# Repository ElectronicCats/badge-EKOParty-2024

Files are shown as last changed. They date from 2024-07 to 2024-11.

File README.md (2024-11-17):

# Badge EKO Party 2024
Badge Oficial de EKOPARTY 2024

## Getting started

1. Connect Badge via USB to your computer.
2. Open the serial port indicated for the badge on your computer through a program such as Arduino IDE, Putty or Screen at 115200 bauds.
3. The badge text should appear in the terminal.

## Tecnologia

- ESP32C6
- LEDs neopixel
- USB
- LoRa
- Buzzer
- OLED

## How to build the firmware

Check the [Developer guide](./firmware/README.md) to learn how to build the firmware from scratch.

## Gratitude
Do you want to say thank you? Tag these companies on social networks and show them your badge, thanks to them it is possible

- [ElectronicCats](https://electroniccats.com/)

## License

Electronic Cats invests time and resources providing this open source design, please support Electronic Cats and open-source hardware by purchasing products from Electronic Cats!

Designed by Electronic Cats.

Hardware released under an CERN Open Hardware Licence v1.2. See the LICENSE_HARDWARE file for more information.

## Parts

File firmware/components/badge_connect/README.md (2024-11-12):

# Badge Connect library (Binary version)

This library is designed to provide a simple API in order to communicate electronic badges over a WiFi mesh network. It works using the [ESPNOW protocol](https://docs.espressif.com/projects/esp-idf/en/stable/esp32/api-reference/network/esp_now.html) developed by Espressif Systems.

## Features

- Send and receive messages between badges (messages can be of any data type)
- Set the badge's type (e.g. "BSides", "DragonJAR", "Ekoparty", and "BugCON")
- Get the badge's type

## Requirements

- At least two ESP32 development boards
- ESP-IDF installed in your computer
- `make` installed in your computer (optional)

## Installation

Add badge_connect_bin as a git submodule in your project.

```bash
git submodule add https://github.com/ElectronicCats/badge_connect_bin.git firmware/components/badge_connect
```

## Usage

1. Include the library in your source code.

```c
#include "badge_connect.h"
```

2. Initialize the library in your code.

```c
badge_connect_init();
```

3. Implement the callback function that will be called when a message is received.

```c
void receive_data_cb(badge_connect_recv_msg_t* msg) {
    // Do something with the received message
}
```

4. Register the callback function.

```c
badge_connect_register_recv_cb(receive_data_cb);
```

5. Set the badge's type, choose one of the following:

```c
badge_connect_set_bsides_badge();
badge_connect_set_dragonjar_badge();
badge_connect_set_ekoparty_badge();
badge_connect_set_bugcon_badge();
```

6. Send a message to another badge.

```c
char* data = "Hello, world!";
badge_connect_send(data, strlen(data));
```

7. Compile and flash!

## Examples

There is a folder called `examples` in this repository, you can use the `Makefile` in each example to compile and flash the firmware.

1. Get `idf.py` to your terminal session, if you followed the Espressif IDF installation guide, use `get_idf`.

```bash
get_idf
```

2. Go to the example folder you want to compile. For example, the `send_int` one.

```bash
cd examples/send_int
```

3. Set the board type you are using, skip if you are using an `ESP32`. For example, `ESP32-C6`.

```bash
idf.py set-target esp32c6
```

4. Set the serial port where the board is connected. For example, `/dev/ttyUSB0`.

```bash
export PORT=/dev/ttyUSB0
```

5. Compile, flash, and monitor the output.

```bash
make all
```

## License

Electronic Cats invests time and resources in providing this open-source design, please support Electronic Cats and open-source hardware by purchasing products from Electronic Cats!

Designed by Electronic Cats.

This library is released under a GNU AGPL v3.0 license. See the [LICENSE](LICENSE) file for more information.

Electronic Cats is a registered trademark, please do not use if you sell these PCBs.

June 2024

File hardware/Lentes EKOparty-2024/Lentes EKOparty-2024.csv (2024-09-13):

Reference | Value | Datasheet | Footprint | Qty | DNP | #LCSC
J2 | Conn_02x03_Odd_Even | ~ | Connector_PinHeader_2.54mm:PinHeader_2x03_P2.54mm_Vertical | 1 |  | C706893

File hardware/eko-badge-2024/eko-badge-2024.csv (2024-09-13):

Reference | Value | Datasheet | Footprint | Qty | DNP | LCSC# | Proveedor | manf#
AE1 | Antenna_Shield |  | Connector_PinHeader_2.54mm:PinHeader_1x01_P2.54mm_Vertical | 1 | DNP | C2913580
C1,C3,C4,C5 | 10uF |  | Capacitor_SMD:C_0603_1608Metric | 4 |  | C85713 | JLCPCB | GRM188R61E106KA73J
C2,C15 | 1uF |  | Capacitor_SMD:C_0603_1608Metric | 2 |  | C15849 | JLCPCB | TMK107BJ105KA8T
C6,C7,C8,C9,C10,C11,C12,C14,C16,C17,C18 | .1uF |  | Capacitor_SMD:C_0603_1608Metric | 11 |  | C478888 | LCSC | 0603F104M500NT
C13 | .22uF |  | Capacitor_SMD:C_0603_1608Metric | 1 |  | C161213 | LCSC
D1 | MBR120 |  | Diode_SMD:D_SOD-123F | 1 |  | C130880 | JLCPCB | MBR120LSFT1G
D2,D3,D4 | WS2812B |  | LED_SMD:LED_WS2812B-Mini_PLCC4_3.5x3.5mm | 3 |  | C527089 | LCSC | WS2812B-Mini
F1 | 1A |  | Fuse:Fuse_0805_2012Metric | 1 |  | C2649564 | JLCPCB | MFU0805FF01000P100
J1 | UART |  | Connector_PinHeader_2.54mm:PinHeader_1x04_P2.54mm_Vertical | 1 | DNP
J2,J7 | Battery |  | Eko2024:BH-AA-A1AJ020 | 2 |  | C5290181 | JLCPCB y LCSC
J3 | Lentes |  | Eko2024:HARWIN_M20-7810345 | 1 |  |  | DIGIKEY | M20-7810345
J4 | OLED |  | Eko2024:Display OLED 128 x32 | 1 |  |  | UNIT | Display OLED 128×32 0.91 I2C SSD1306 Blanco / Azul
J5,J6 | Add-On |  | Connector_PinSocket_2.54mm:PinSocket_2x03_P2.54mm_Vertical_SMD | 2 |  | C3975148
LS1 | 931-SPKM.20.8.A-ND |  | Connector_PinHeader_2.54mm:PinHeader_1x02_P2.54mm_Vertical | 1 |  |  |  | 931-SPKM.20.8.A-ND
P1 | USB_C_Plug_USB2.0 |  | Eko2024:C393939 | 1 |  | C393939 | LCSC | TYPE-C-31-M-31
Q1 | DMG3415U-7 |  | Package_TO_SOT_SMD:SOT-23 | 1 |  | C96616 | JLCPCB | DMG3415UQ-7
R1 | 100K |  | Resistor_SMD:R_0603_1608Metric | 1 |  | C25803 | JLCPCB | RC0603DR-07100KL
R2 | 10K |  | Resistor_SMD:R_0603_1608Metric | 1 |  | C217281
R3,R4 | 5k1 |  | Resistor_SMD:R_0603_1608Metric | 2 |  | C191782 |  | ERJ3RBD5101V
R5 | 47K |  | Resistor_SMD:R_0603_1608Metric | 1 |  | C25819
R6 | 22K |  | Resistor_SMD:R_0603_1608Metric | 1 |  | C912502
R7 | 470 |  | Resistor_SMD:R_0603_1608Metric | 1 |  | C103661 |  | RTT03471JTP
R8 | 3.3K |  | Resistor_SMD:R_0603_1608Metric | 1 |  | C403480 | JLCPCB | ERJ-3GEYJ332V
SW1 | ON |  | Eko2024:MSK12C02 | 1 |  | C431540 | JLCPCB
SW2 | LEFT |  | Button_Switch_SMD:SW_SPST_TL3342 | 1 |  | C318889 | LCSC
SW3 | UP |  | Button_Switch_SMD:SW_SPST_TL3342 | 1 |  | C318889 | LCSC
SW4 | DOWN |  | Button_Switch_SMD:SW_SPST_TL3342 | 1 |  | C318889 | LCSC
SW5 | RESET |  | Button_Switch_SMD:SW_SPST_TL3342 | 1 |  | C318889 | LCSC
SW6 | BOOT |  | Button_Switch_SMD:SW_SPST_TL3342 | 1 |  | C318889 | LCSC
SW7 | RIGTH |  | Button_Switch_SMD:SW_SPST_TL3342 | 1 |  | C318889 | LCSC
U1 | ESP32-C6-WROOM-1-N4 |  | bsides:XCVR_ESP32-C6-WROOM-1-N8 | 1 |  |  | Mouser | ESP32-C6-WROOM-1-N4
U2 | XC6220B331MR-G |  | Package_TO_SOT_SMD:SOT-23-5 | 1 |  | C86534 | JLCPCB | XC6220B331MR-G
U3 | RFM95W-915S2 |  | RF_Module:HOPERF_RFM9XW_SMD | 1 |  |  | Mouser | 109990166
U4 | TPA321 |  | Package_SO:SOP-8_3.9x4.9mm_P1.27mm | 1 |  | C2873032 | Mouser | TPA321D

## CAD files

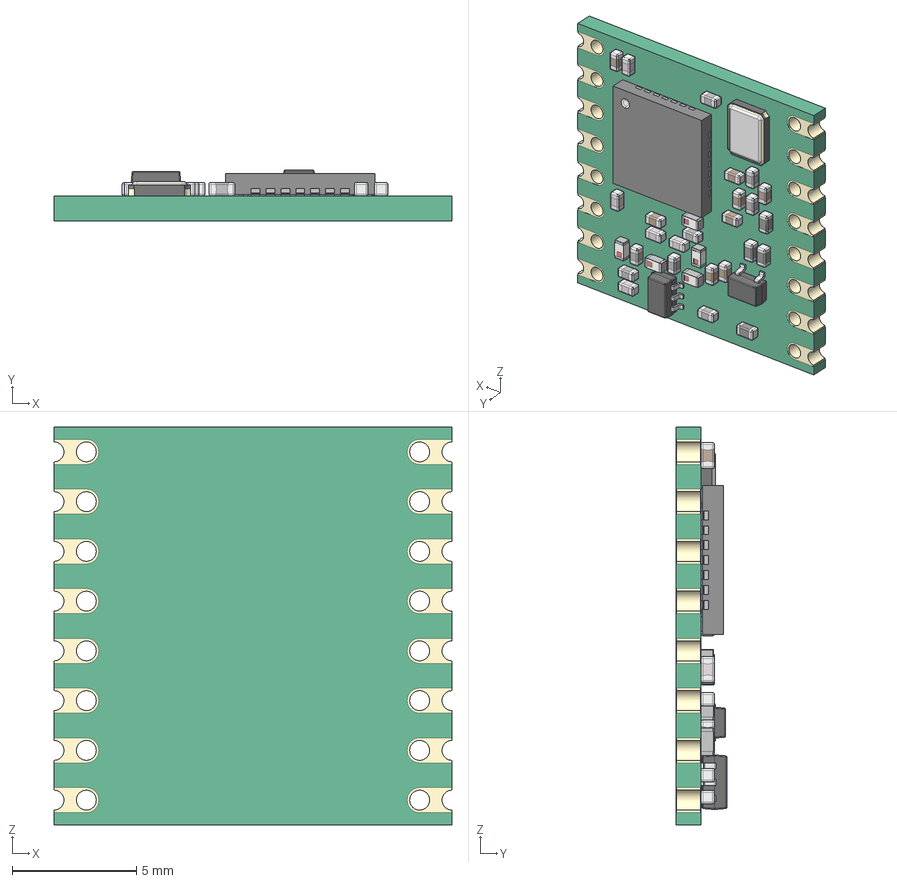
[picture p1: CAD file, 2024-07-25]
hardware/3D/RFM95 LoRa v15.step
16.0 x 2.04 x 16.0 mm
QFN 28
SMD Crystal
CAP 0403 x 8
CAP Ceramic 0403 x 8
Res 0403 x 4
CAP ML 0403 x 5
SOT-323
Inductor SMD 0403 x 5
SOT-363

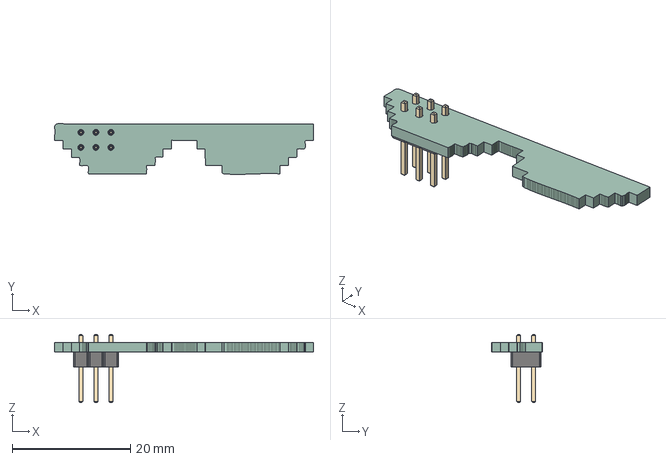
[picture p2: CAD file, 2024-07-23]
hardware/Lentes EKOparty-2024/Lentes EKOparty-2024.step
43.8 x 8.58 x 11.5 mm
PinHeader_2x03_P254mm_Vertical
Lentes EKOparty-2024_PCB

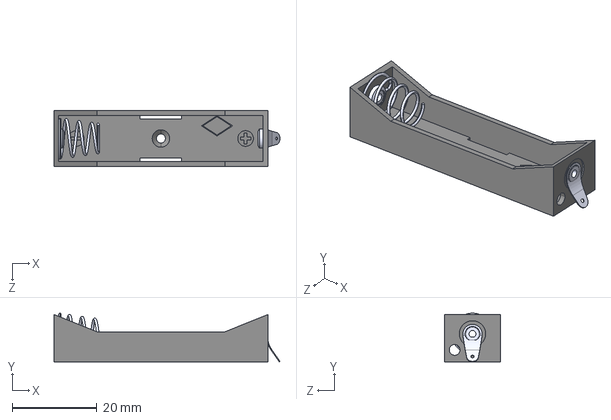
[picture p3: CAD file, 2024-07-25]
hardware/3D/BCAAAL.step
53.4 x 11.5 x 13.2 mm

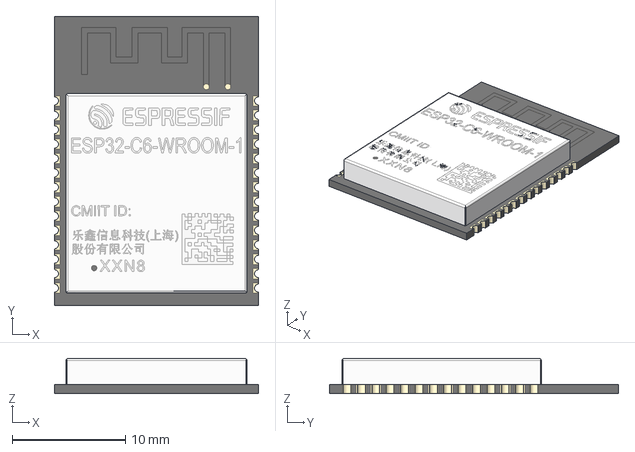
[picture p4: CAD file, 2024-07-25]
hardware/3D/ESP32-C6-WROOM-1-N4.step
18.0 x 25.5 x 3.11 mm

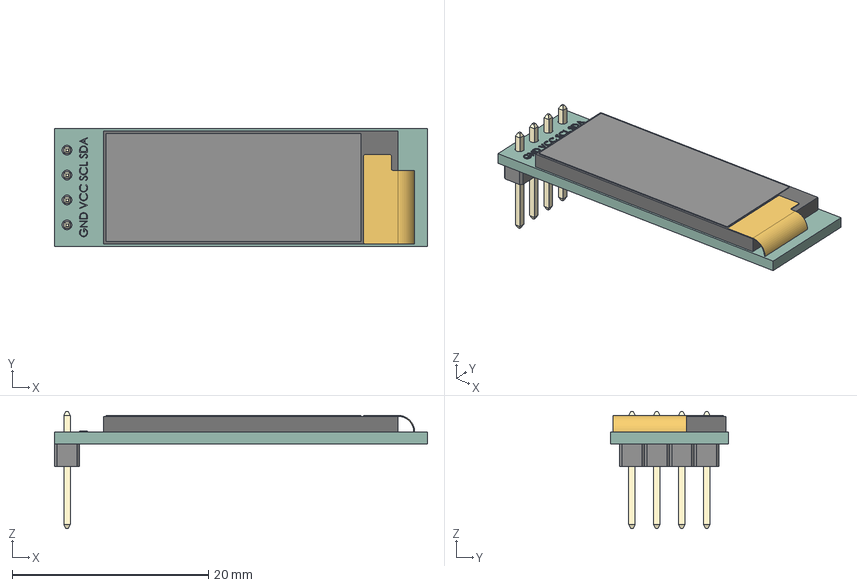
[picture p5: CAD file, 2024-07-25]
hardware/3D/128x32-OLED.STEP
38.0 x 12.0 x 11.9 mm

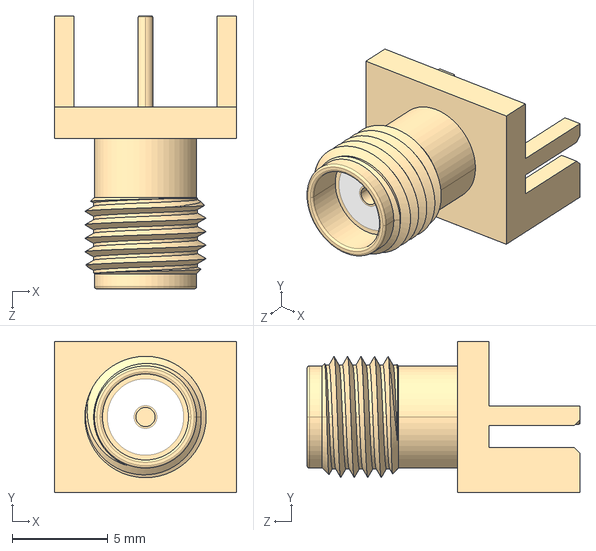
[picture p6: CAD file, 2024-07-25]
hardware/3D/2985-6036.STEP
9.53 x 7.92 x 14.3 mm

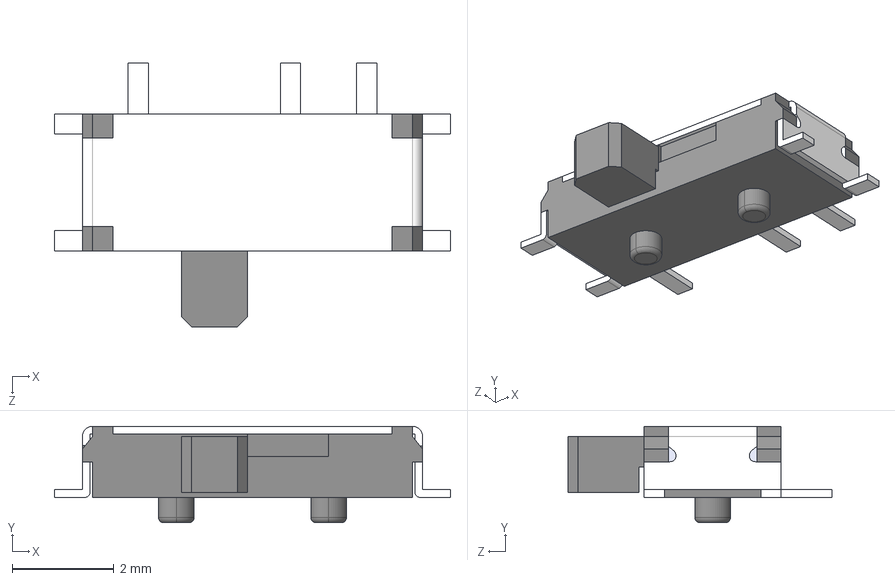
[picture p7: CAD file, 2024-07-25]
hardware/3D/MSK12C02.stp
7.80 x 1.90 x 5.20 mm

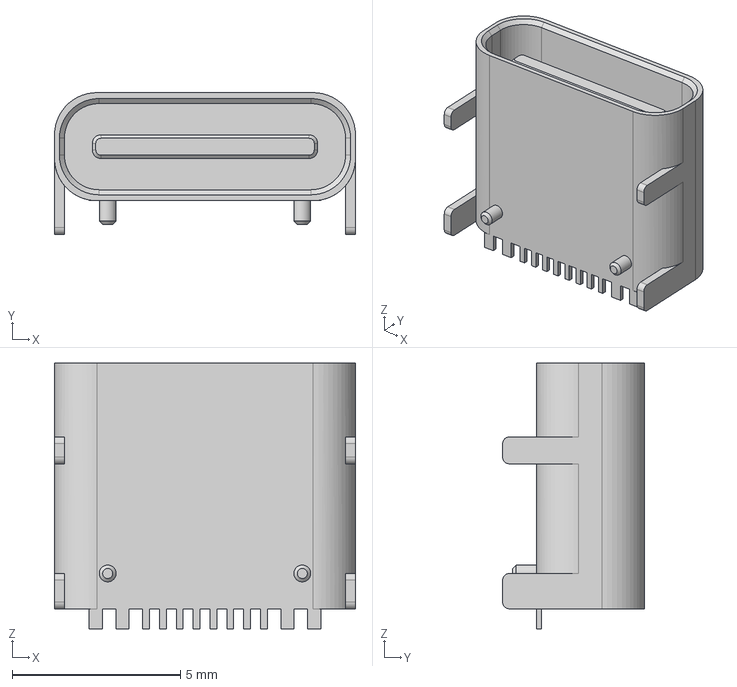
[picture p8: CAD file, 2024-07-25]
hardware/3D/HRO TYPE-C-31-M-12.step
8.94 x 4.21 x 7.90 mm

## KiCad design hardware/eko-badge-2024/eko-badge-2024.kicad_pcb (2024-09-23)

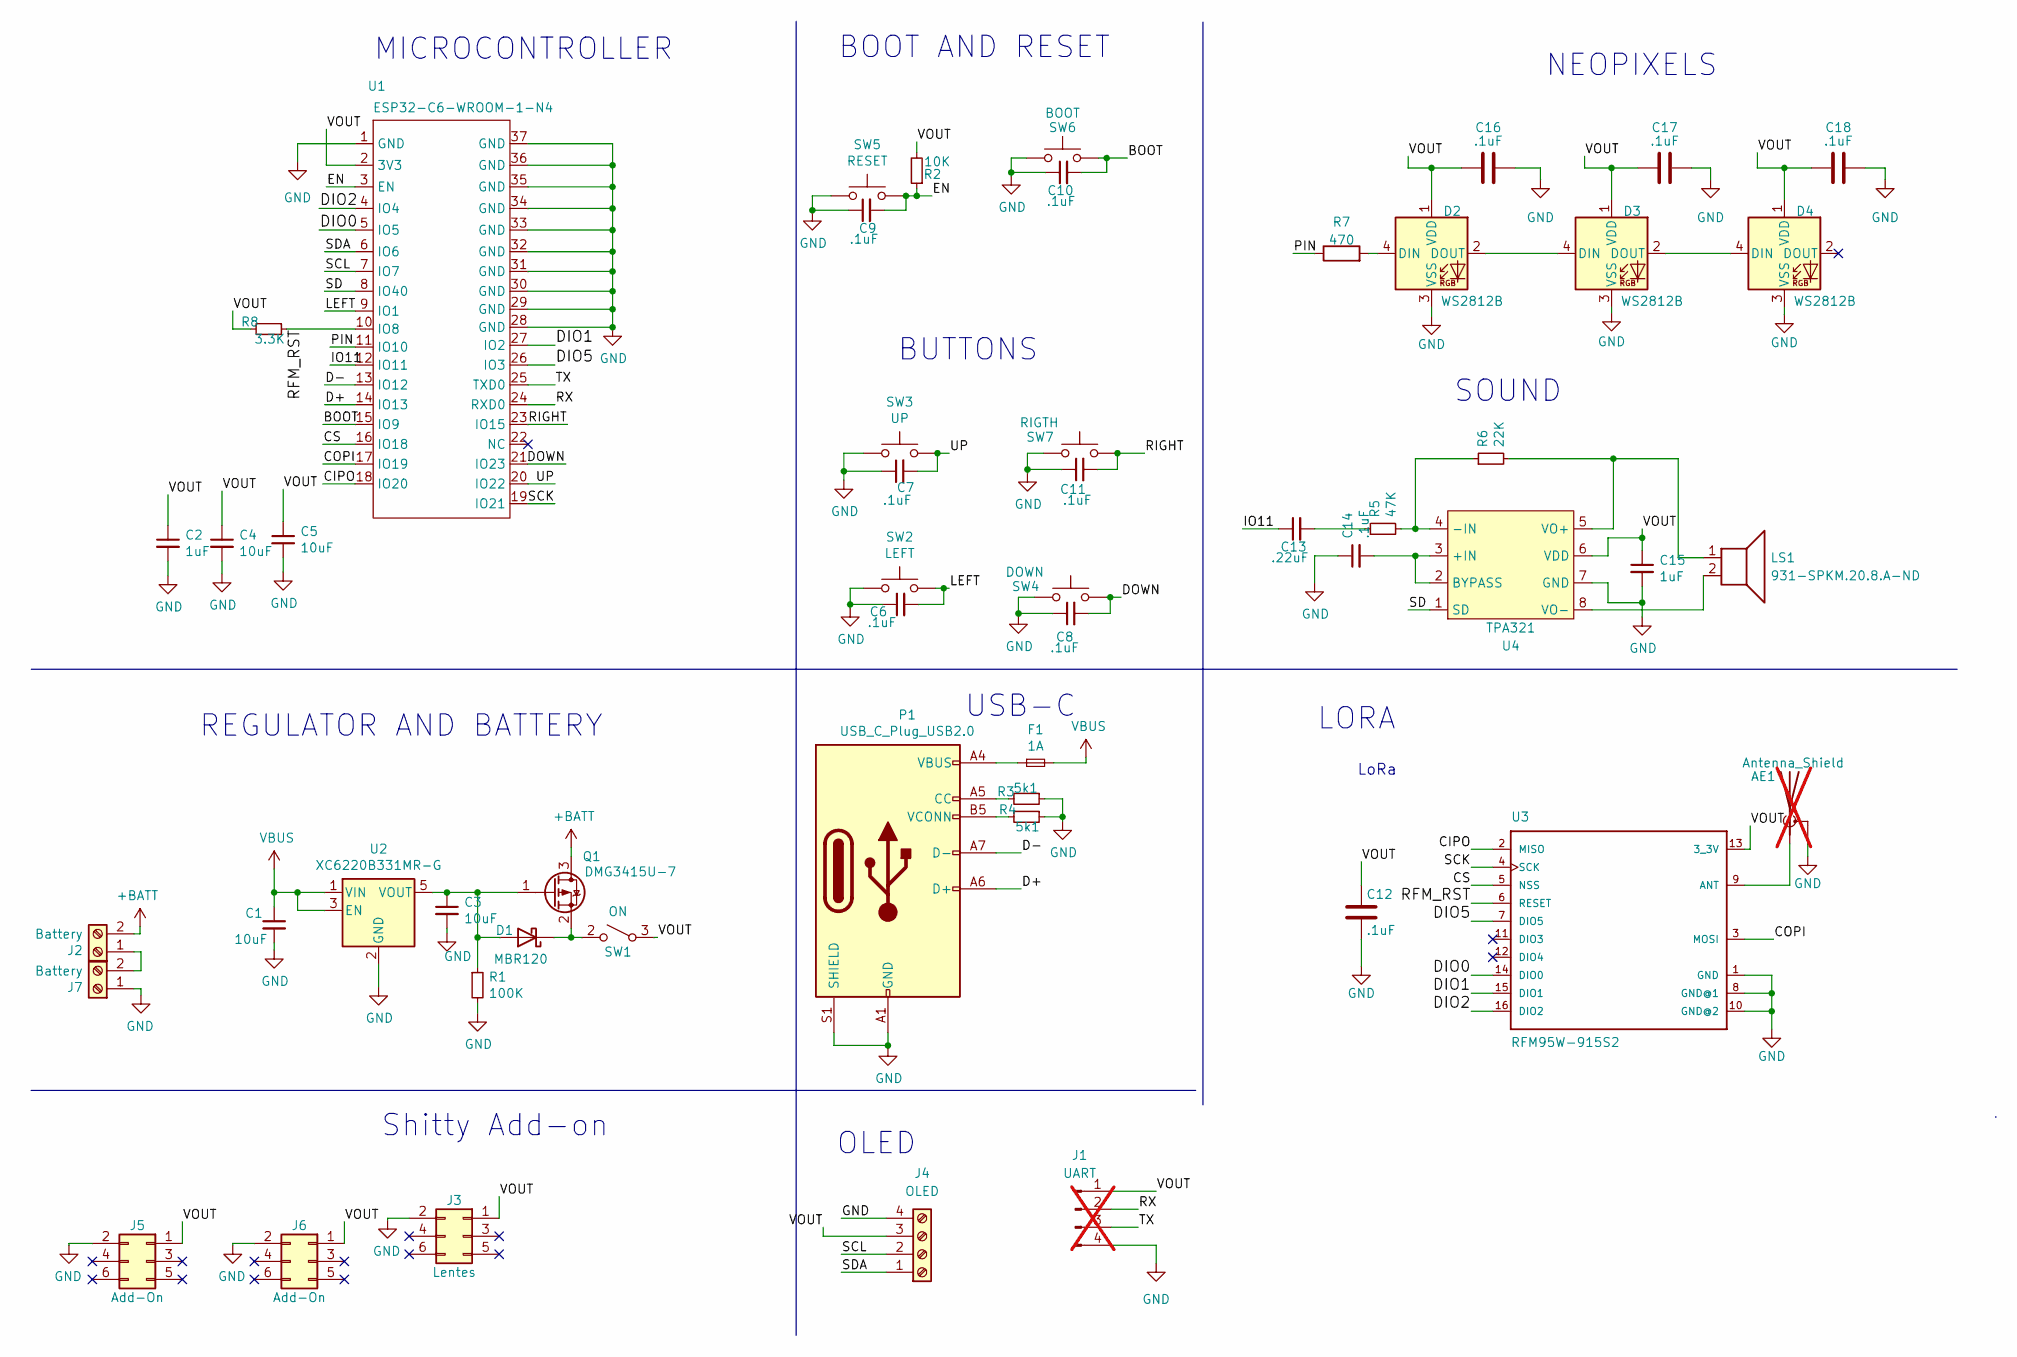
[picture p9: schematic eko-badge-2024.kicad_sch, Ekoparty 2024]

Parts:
AE1: Antenna_Shield; PinHeader_1x01_P2.54mm_Vertical; LCSC# C2913580; not fitted
C1, C3, C4, C5: 10uF; C_0603_1608Metric; LCSC# C85713
C2, C15: 1uF; C_0603_1608Metric; LCSC# C15849
C6, C7, C8, C9, C10, C11, C12, C14, C16, C17, C18: .1uF; C_0603_1608Metric; LCSC# C478888
C13: .22uF; C_0603_1608Metric; LCSC# C161213
D1: MBR120; D_SOD-123F; LCSC# C130880
D2, D3, D4: WS2812B; LED_WS2812B-Mini_PLCC4_3.5x3.5mm; LCSC# C527089
F1: 1A; Fuse_0805_2012Metric; LCSC# C2649564
J1: UART; PinHeader_1x04_P2.54mm_Vertical; not fitted
J2, J7: Battery; BH-AA-A1AJ020; LCSC# C5290181
J3: Lentes; HARWIN_M20-7810345
J4: OLED; Display OLED 128 x32
J5, J6: Add-On; PinSocket_2x03_P2.54mm_Vertical_SMD; LCSC# C3975148
LS1: 931-SPKM.20.8.A-ND; PinHeader_1x02_P2.54mm_Vertical
P1: USB_C_Plug_USB2.0; C393939; LCSC# C393939
Q1: DMG3415U-7; SOT-23; LCSC# C96616
R1: 100K; R_0603_1608Metric; LCSC# C25803
R2: 10K; R_0603_1608Metric; LCSC# C217281
R3, R4: 5k1; R_0603_1608Metric; LCSC# C191782
R5: 47K; R_0603_1608Metric; LCSC# C25819
R6: 22K; R_0603_1608Metric; LCSC# C912502
R7: 470; R_0603_1608Metric; LCSC# C103661
R8: 3.3K; R_0603_1608Metric; LCSC# C403480
SW1: ON; MSK12C02; LCSC# C431540
SW2: LEFT; SW_SPST_TL3342; LCSC# C318889
SW3: UP; SW_SPST_TL3342; LCSC# C318889
SW4: DOWN; SW_SPST_TL3342; LCSC# C318889
SW5: RESET; SW_SPST_TL3342; LCSC# C318889
SW6: BOOT; SW_SPST_TL3342; LCSC# C318889
SW7: RIGTH; SW_SPST_TL3342; LCSC# C318889
U1: ESP32-C6-WROOM-1-N4; XCVR_ESP32-C6-WROOM-1-N8
U2: XC6220B331MR-G; SOT-23-5; LCSC# C86534
U3: RFM95W-915S2; HOPERF_RFM9XW_SMD
U4: TPA321; SOP-8_3.9x4.9mm_P1.27mm; LCSC# C2873032

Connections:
+BATT: J2.2, Q1.3 (D)
/BOOT: C10.2, SW6.2, U1.15 (IO9)
/CIPO: U1.18 (IO20), U3.2 (MISO)
/COPI: U1.17 (IO19), U3.3 (MOSI)
/CS: U1.16 (IO18), U3.5 (NSS)
/D+: P1.A6 (D+), U1.14 (IO13)
/D-: P1.A7 (D-), U1.13 (IO12)
/DIO0: U1.5 (IO5), U3.14 (DIO0)
/DIO1: U1.27 (IO2), U3.15 (DIO1)
/DIO2: U1.4 (IO4), U3.16 (DIO2)
/DIO5: U1.26 (IO3), U3.7 (DIO5)
/DOWN: C8.2, SW4.2, U1.21 (IO23)
/EN: C9.2, R2.1, SW5.2, U1.3 (EN)
/IO11: C13.1, U1.12 (IO11)
/LEFT: C6.2, SW2.2, U1.9 (IO1)
/PIN: R7.1, U1.11 (IO10)
/RFM_RST: R8.1, U1.10 (IO8), U3.6 (RESET)
/RIGHT: C11.2, SW7.2, U1.23 (IO15)
/RX: J1.2, U1.24 (RXD0)
/SCK: U1.19 (IO21), U3.4 (SCK)
/SCL: J4.2, U1.7 (IO7)
/SD: U1.8 (IO40), U4.1 (SD)
/SDA: J4.1, U1.6 (IO6)
/TX: J1.3, U1.25 (TXD0)
/UP: C7.2, SW3.2, U1.20 (IO22)
/VOUT: C2.1, C4.1, C5.1, C12.1, C15.1, C16.2, C17.2, C18.2, D2.1 (VDD), D3.1 (VDD), D4.1 (VDD), J1.1, J3.1, J4.3, J5.1, J6.1, R2.2, R8.2, SW1.3 (A), U1.2 (3V3), U3.13 (3_3V), U4.6 (VDD)
GND: AE1.2 (Shield), C1.2, C2.2, C3.2, C4.2, C5.2, C6.1, C7.1, C8.1, C9.1, C10.1, C11.1, C12.2, C14.1, C15.2, C16.1, C17.1, C18.1, D2.3 (VSS), D3.3 (VSS), D4.3 (VSS), J1.4, J3.2, J4.4, J5.2, J6.2, J7.1, P1.A1 (GND), P1.A12 (GND), P1.B1 (GND), P1.B12 (GND), P1.S1 (SHIELD), R1.2, R3.1, R4.1, SW2.1, SW3.1, SW4.1, SW5.1, SW6.1, SW7.1, U1.1 (GND), U1.28 (GND), U1.29 (GND), U1.30 (GND), U1.31 (GND), U1.32 (GND), U1.33 (GND), U1.34 (GND), U1.35 (GND), U1.36 (GND), U1.37 (GND), U2.2 (GND), U3.1 (GND), U3.8 (GND@1), U3.10 (GND@2), U4.7 (GND)
unnamed: AE1.1 (A), U3.9 (ANT)
unnamed: C13.2, R5.1
unnamed: C3.1, D1.2 (A), Q1.1 (G), R1.1, U2.5 (VOUT)
unnamed: D1.1 (K), Q1.2 (S), SW1.2 (B)
unnamed: D2.4 (DIN), R7.2
unnamed: D2.2 (DOUT), D3.4 (DIN)
unnamed: D3.2 (DOUT), D4.4 (DIN)
unnamed: F1.1, P1.A4 (VBUS), P1.A9 (VBUS), P1.B4 (VBUS), P1.B9 (VBUS)
unnamed: J2.1, J7.2
unnamed: P1.A5 (CC), R3.2
unnamed: P1.B5 (VCONN), R4.2
unnamed: C14.2, U4.2 (BYPASS), U4.3 (+IN)
unnamed: R5.2, R6.1, U4.4 (-IN)
unnamed: LS1.1, R6.2, U4.5 (VO+)
unnamed: LS1.2, U4.8 (VO-)
VBUS: C1.1, F1.2, U2.1 (VIN), U2.3 (EN)

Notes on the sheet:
MICROCONTROLLER
LoRa
OLED
USB-C
BUTTONS
SOUND
LORA
NEOPIXELS
REGULATOR AND BATTERY
Shitty Add-on
BOOT AND RESET

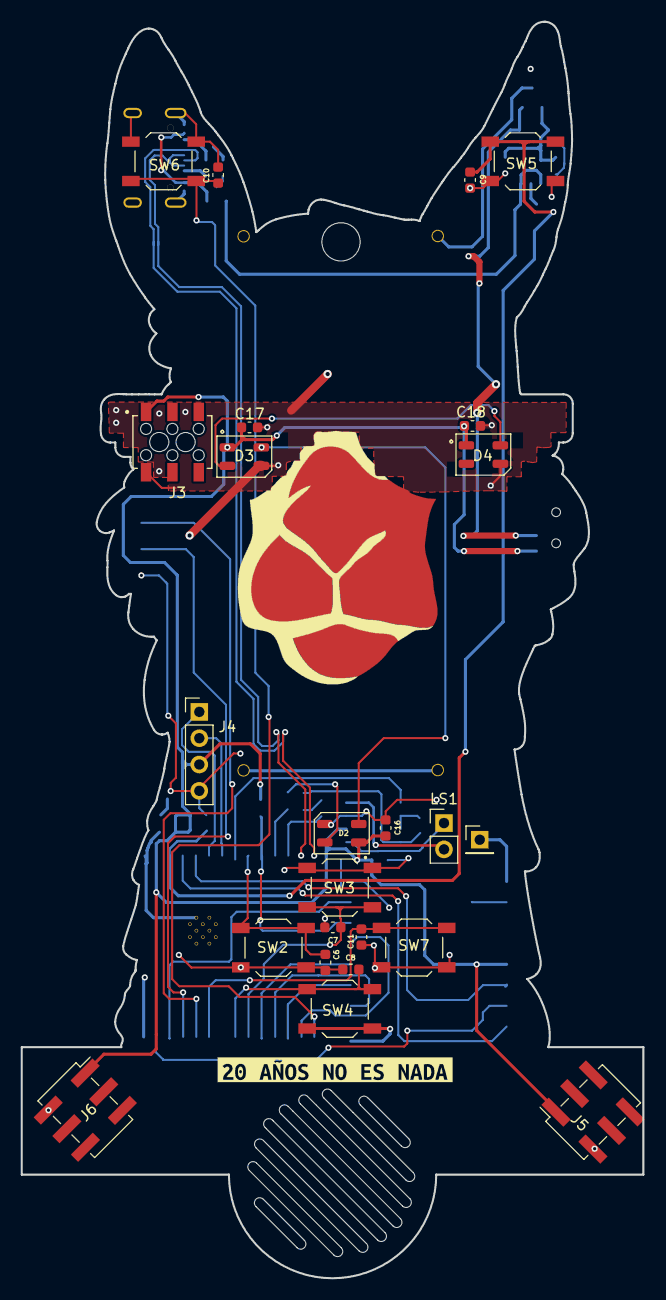
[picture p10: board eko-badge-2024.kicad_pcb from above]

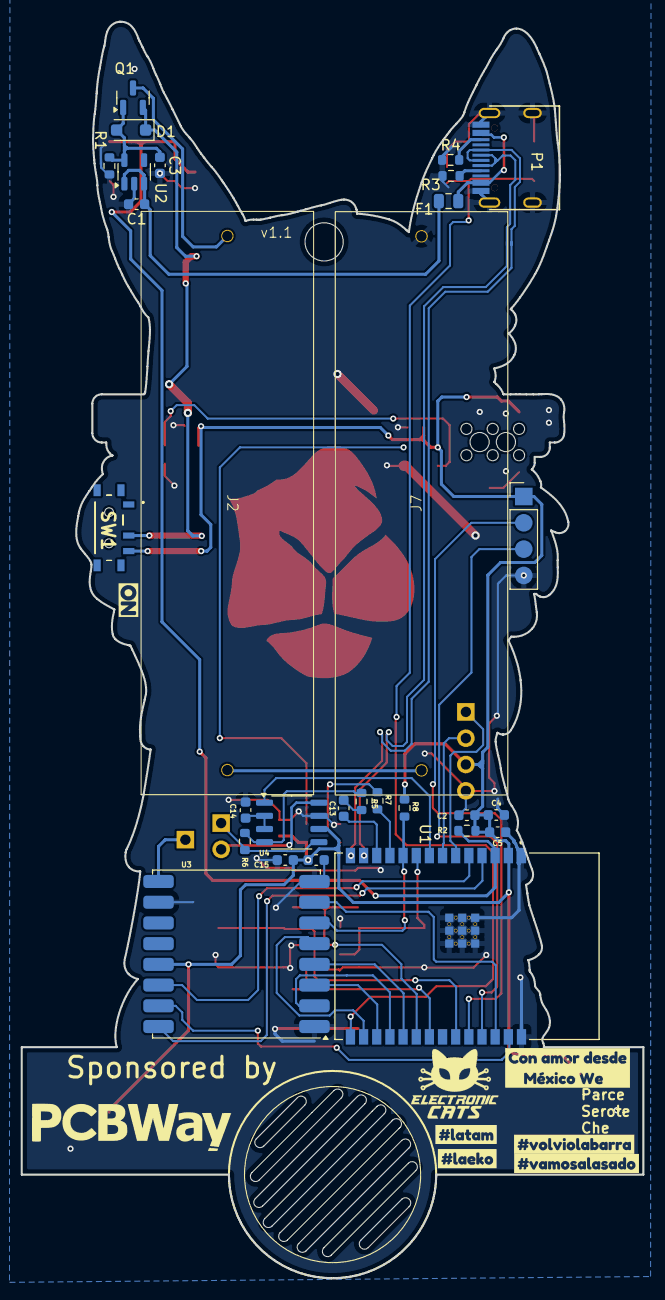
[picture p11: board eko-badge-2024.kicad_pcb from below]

Board: 2 copper layers, 60.0 x 121.3 mm, 61 parts (35 on the bottom side), 43 nets.

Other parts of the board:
Ref**: Val**; llama mask flaca
kibuzzard-66BD383E: G***; kibuzzard-66BD383E
kibuzzard-66D7A032: G***; kibuzzard-66D7A032
kibuzzard-66D79F5F: G***; kibuzzard-66D79F5F
kibuzzard-66D79F47: G***; kibuzzard-66D79F47
kibuzzard-66D79F90: G***; kibuzzard-66D79F90
kibuzzard-66D79FA5: G***; kibuzzard-66D79FA5
kibuzzard-66E4B147: G***; kibuzzard-66E4B147

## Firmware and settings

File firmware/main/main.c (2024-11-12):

#include <stdio.h>

#include "badge_connect.h"
#include "badge_link_module.h"
#include "buzzer.h"
#include "cat_console.h"
#include "esp_log.h"
#include "esp_timer.h"
#include "flame.h"
#include "flash_fs.h"
#include "flash_fs_screens.h"
#include "keyboard_module.h"
#include "llamaneitor.h"
#include "lora_manager.h"
#include "menus_module.h"
#include "neopixels_events.h"
#include "neopixels_module.h"
#include "oled_screen.h"
#include "open_thread.h"
#include "preferences.h"
#include "screen_saver.h"
#include "sd_card.h"
#include "sounds.h"
#include "toast.h"
#include "web_file_browser.h"
#include "wifi_app.h"
#include "mission_two.h"
#include "adv_scan_module.h"

#include "villages.h"

static const char *TAG = "main";

void app_main() {
#if !defined(CONFIG_MAIN_DEBUG)
  esp_log_level_set(TAG, ESP_LOG_NONE);
#endif
  preferences_begin();
  if (preferences_get_int("dp_select", 0) == 0) {
    preferences_put_int("dp_select", 6);
  }
  flash_fs_begin(flash_fs_screens_handler);
  sd_card_begin();
  keyboard_module_begin();
  menus_module_begin();
  if (!preferences_get_int("flogin", 0)) {
    screen_saver_stop();
  }
  preferences_put_bool("wifi_connected", false);
  neopixels_module_begin();
  neopixels_set_pixels(MAX_LED_NUMBER, 0, 0, 0);
  neopixels_refresh();

  villages_begin();
  lora_module_begin();
  buzzer_enable();
  buzzer_begin(11);
  // This to show the history on first boot and until the user completes the
  // history
  if (!preferences_get_int("flogin", 0)) {
    llamaneitor_begin();
  }
  toast_begin();
  flame_task_begin();
  // adv_scanner_module_begin();
  // Always start the console at the end
  // cat_console_begin();
  // play_artu();
}

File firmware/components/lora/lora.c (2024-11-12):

#include "freertos/FreeRTOS.h"
#include "freertos/task.h"
#include "esp_system.h"
#include "driver/spi_master.h"
#include "soc/gpio_struct.h"
#include "driver/gpio.h"
#include <string.h>

/*
 * Register definitions
 */
#define REG_FIFO                       0x00
#define REG_OP_MODE                    0x01
#define REG_FRF_MSB                    0x06
#define REG_FRF_MID                    0x07
#define REG_FRF_LSB                    0x08
#define REG_PA_CONFIG                  0x09
#define REG_LNA                        0x0c
#define REG_FIFO_ADDR_PTR              0x0d
#define REG_FIFO_TX_BASE_ADDR          0x0e
#define REG_FIFO_RX_BASE_ADDR          0x0f
#define REG_FIFO_RX_CURRENT_ADDR       0x10
#define REG_IRQ_FLAGS                  0x12
#define REG_RX_NB_BYTES                0x13
#define REG_PKT_SNR_VALUE              0x19
#define REG_PKT_RSSI_VALUE             0x1a
#define REG_MODEM_CONFIG_1             0x1d
#define REG_MODEM_CONFIG_2             0x1e
#define REG_PREAMBLE_MSB               0x20
#define REG_PREAMBLE_LSB               0x21
#define REG_PAYLOAD_LENGTH             0x22
#define REG_MODEM_CONFIG_3             0x26
#define REG_RSSI_WIDEBAND              0x2c
#define REG_DETECTION_OPTIMIZE         0x31
#define REG_DETECTION_THRESHOLD        0x37
#define REG_SYNC_WORD                  0x39
#define REG_DIO_MAPPING_1              0x40
#define REG_VERSION                    0x42

/*
 * Transceiver modes
 */
#define MODE_LONG_RANGE_MODE           0x80
#define MODE_SLEEP                     0x00
#define MODE_STDBY                     0x01
#define MODE_TX                        0x03
#define MODE_RX_CONTINUOUS             0x05
#define MODE_RX_SINGLE                 0x06

/*
 * PA configuration
 */
#define PA_BOOST                       0x80

/*
 * IRQ masks
 */
#define IRQ_TX_DONE_MASK               0x08
#define IRQ_PAYLOAD_CRC_ERROR_MASK     0x20
#define IRQ_RX_DONE_MASK               0x40

#define PA_OUTPUT_RFO_PIN              0
#define PA_OUTPUT_PA_BOOST_PIN         1

#define TIMEOUT_RESET                  100

static spi_device_handle_t __spi;

static int __implicit;
static long __frequency;

/**
 * Write a value to a register.
 * @param reg Register index.
 * @param val Value to write.
 */
void 
lora_write_reg(int reg, int val)
{
   uint8_t out[2] = { 0x80 | reg, val };
   uint8_t in[2];

   spi_transaction_t t = {
      .flags = 0,
      .length = 8 * sizeof(out),
      .tx_buffer = out,
      .rx_buffer = in  
   };

   gpio_set_level(CONFIG_CS_GPIO, 0);
   spi_device_transmit(__spi, &t);
   gpio_set_level(CONFIG_CS_GPIO, 1);
}

/**
 * Read the current value of a register.
 * @param reg Register index.
 * @return Value of the register.
 */
int
lora_read_reg(int reg)
{
   uint8_t out[2] = { reg, 0xff };
   uint8_t in[2];

   spi_transaction_t t = {
      .flags = 0,
      .length = 8 * sizeof(out),
      .tx_buffer = out,
      .rx_buffer = in
   };

   gpio_set_level(CONFIG_CS_GPIO, 0);
   spi_device_transmit(__spi, &t);
   gpio_set_level(CONFIG_CS_GPIO, 1);
   return in[1];
}

/**
 * Perform physical reset on the Lora chip
 */
void 
lora_reset(void)
{
   gpio_set_level(CONFIG_RST_GPIO, 0);
   vTaskDelay(pdMS_TO_TICKS(1));
   gpio_set_level(CONFIG_RST_GPIO, 1);
   vTaskDelay(pdMS_TO_TICKS(10));
}

/**
 * Configure explicit header mode.
 * Packet size will be included in the frame.
 */
void 
lora_explicit_header_mode(void)
{
   __implicit = 0;
   lora_write_reg(REG_MODEM_CONFIG_1, lora_read_reg(REG_MODEM_CONFIG_1) & 0xfe);
}

/**
 * Configure implicit header mode.
 * All packets will have a predefined size.
 * @param size Size of the packets.
 */
void 
lora_implicit_header_mode(int size)
{
   __implicit = 1;
   lora_write_reg(REG_MODEM_CONFIG_1, lora_read_reg(REG_MODEM_CONFIG_1) | 0x01);
   lora_write_reg(REG_PAYLOAD_LENGTH, size);
}

/**
 * Sets the radio transceiver in idle mode.
 * Must be used to change registers and access the FIFO.
 */
void 
lora_idle(void)
{
   lora_write_reg(REG_OP_MODE, MODE_LONG_RANGE_MODE | MODE_STDBY);
}

/**
 * Sets the radio transceiver in sleep mode.
 * Low power consumption and FIFO is lost.
 */
void 
lora_sleep(void)
{ 
   lora_write_reg(REG_OP_MODE, MODE_LONG_RANGE_MODE | MODE_SLEEP);
}

/**
 * Sets the radio transceiver in receive mode.
 * Incoming packets will be received.
 */
void 
lora_receive(void)
{
   lora_write_reg(REG_OP_MODE, MODE_LONG_RANGE_MODE | MODE_RX_CONTINUOUS);
}

/**
 * Configure power level for transmission
 * @param level 2-17, from least to most power
 */
void 
lora_set_tx_power(int level)
{
   // RF9x module uses PA_BOOST pin
   if (level < 2) level = 2;
   else if (level > 17) level = 17;
   lora_write_reg(REG_PA_CONFIG, PA_BOOST | (level - 2));
}

/**
 * Set carrier frequency.
 * @param frequency Frequency in Hz
 */
void 
lora_set_frequency(long frequency)
{
   __frequency = frequency;

   uint64_t frf = ((uint64_t)frequency << 19) / 32000000;

   lora_write_reg(REG_FRF_MSB, (uint8_t)(frf >> 16));
   lora_write_reg(REG_FRF_MID, (uint8_t)(frf >> 8));
   lora_write_reg(REG_FRF_LSB, (uint8_t)(frf >> 0));
}

/**
 * Set spreading factor.
 * @param sf 6-12, Spreading factor to use.
 */
void 
lora_set_spreading_factor(int sf)
{
   if (sf < 6) sf = 6;
   else if (sf > 12) sf = 12;

   if (sf == 6) {
      lora_write_reg(REG_DETECTION_OPTIMIZE, 0xc5);
      lora_write_reg(REG_DETECTION_THRESHOLD, 0x0c);
   } else {
      lora_write_reg(REG_DETECTION_OPTIMIZE, 0xc3);
      lora_write_reg(REG_DETECTION_THRESHOLD, 0x0a);
   }

   lora_write_reg(REG_MODEM_CONFIG_2, (lora_read_reg(REG_MODEM_CONFIG_2) & 0x0f) | ((sf << 4) & 0xf0));
}

/**
 * Set bandwidth (bit rate)
 * @param sbw Bandwidth in Hz (up to 500000)
 */
void 
lora_set_bandwidth(long sbw)
{
   int bw;

   if (sbw <= 7.8E3) bw = 0;
   else if (sbw <= 10.4E3) bw = 1;
   else if (sbw <= 15.6E3) bw = 2;
   else if (sbw <= 20.8E3) bw = 3;
   else if (sbw <= 31.25E3) bw = 4;
   else if (sbw <= 41.7E3) bw = 5;
   else if (sbw <= 62.5E3) bw = 6;
   else if (sbw <= 125E3) bw = 7;
   else if (sbw <= 250E3) bw = 8;
   else bw = 9;
   lora_write_reg(REG_MODEM_CONFIG_1, (lora_read_reg(REG_MODEM_CONFIG_1) & 0x0f) | (bw << 4));
}

/**
 * Set coding rate 
 * @param denominator 5-8, Denominator for the coding rate 4/x
 */ 
void 
lora_set_coding_rate(int denominator)
{
   if (denominator < 5) denominator = 5;
   else if (denominator > 8) denominator = 8;

   int cr = denominator - 4;
   lora_write_reg(REG_MODEM_CONFIG_1, (lora_read_reg(REG_MODEM_CONFIG_1) & 0xf1) | (cr << 1));
}

/**
 * Set the size of preamble.
 * @param length Preamble length in symbols.
 */
void 
lora_set_preamble_length(long length)
{
   lora_write_reg(REG_PREAMBLE_MSB, (uint8_t)(length >> 8));
   lora_write_reg(REG_PREAMBLE_LSB, (uint8_t)(length >> 0));
}

/**
 * Change radio sync word.
 * @param sw New sync word to use.
 */
void 
lora_set_sync_word(int sw)
{
   lora_write_reg(REG_SYNC_WORD, sw);
}
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

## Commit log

2024-04-29 feat(hw): init schematic 20 años de la eko!
    [eko-badge-2024.kicad_pcb, eko-badge-2024.kicad_sch]
2024-08-15 feat(Hw): Update lentes
    [Lentes EKOparty-2024.kicad_pcb]
2024-08-15 feat(Hw): Change shitty add on
    [eko-badge-2024.kicad_pcb]
2024-08-16 feat(Hw): Update route
    [eko-badge-2024.kicad_pcb]
2024-08-16 feat(Hw): Update PCB
    [eko-badge-2024.kicad_pcb, eko-badge-2024.kicad_sch]
2024-08-16 feat(Hw): Update BOM
    [eko-badge-2024.kicad_sch]
2024-08-16 fix(hw): update RFM95 module version to 915
    [eko-badge-2024.kicad_sch]
2024-09-03 feat(hw): add logo pcbway and EC
    [eko-badge-2024.kicad_pcb]
2024-09-03 feat: update labels
    [eko-badge-2024.kicad_pcb]
2024-09-17 feat: add logo pcbway
    [Lentes EKOparty-2024.kicad_pcb]
2024-10-08 feat: Add first core
    [partitions.csv, partitions_no_ota.csv]
2024-10-10 feat: add neopixels
    avoid merge conflicts
    [main.c]
2024-10-22 feat: Fix neopixels animation
    [main.c]
2024-10-24 feat: set current llamaneitor scene
2024-10-28 feat: weaken flame by button pulses
2024-10-29 feat: add solderin iron image
